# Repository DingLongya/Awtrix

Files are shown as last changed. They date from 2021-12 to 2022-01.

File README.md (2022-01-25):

# Awtrix

- 官网 https://awtrixdocs.blueforcer.de/
- 参考 UP 三三三三三文啊 视频：https://www.bilibili.com/video/BV1764y1f7pc
- 教程 https://bbs.iobroker.cn/t/topic/3888

## 成品展示

B 站演示地址：  https://b23.tv/A57vieg

这是还没有加外壳，3D打印外壳很贵很贵，想自己用木板做

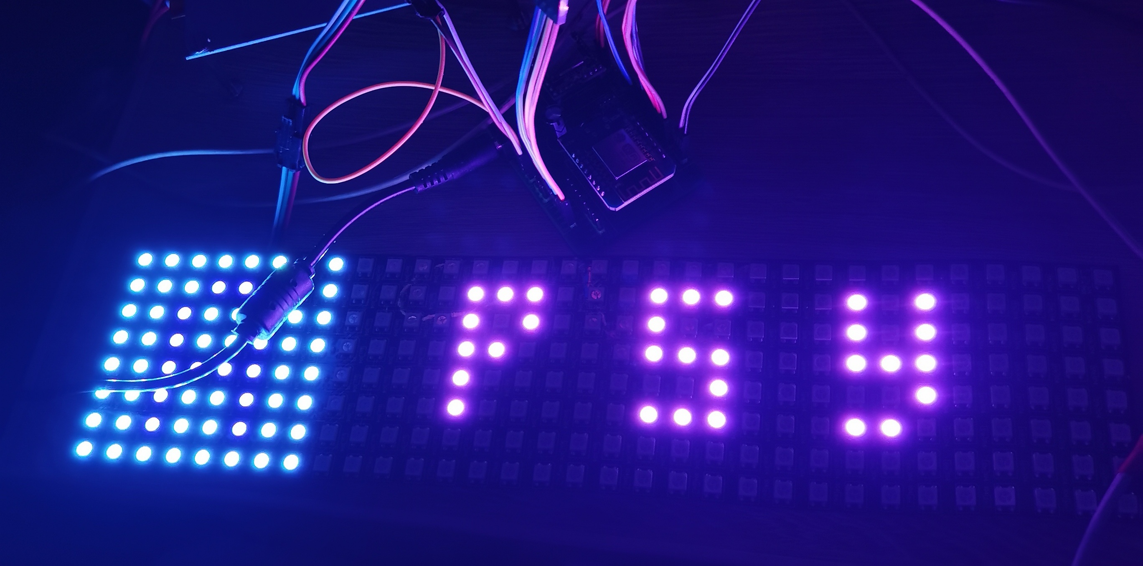
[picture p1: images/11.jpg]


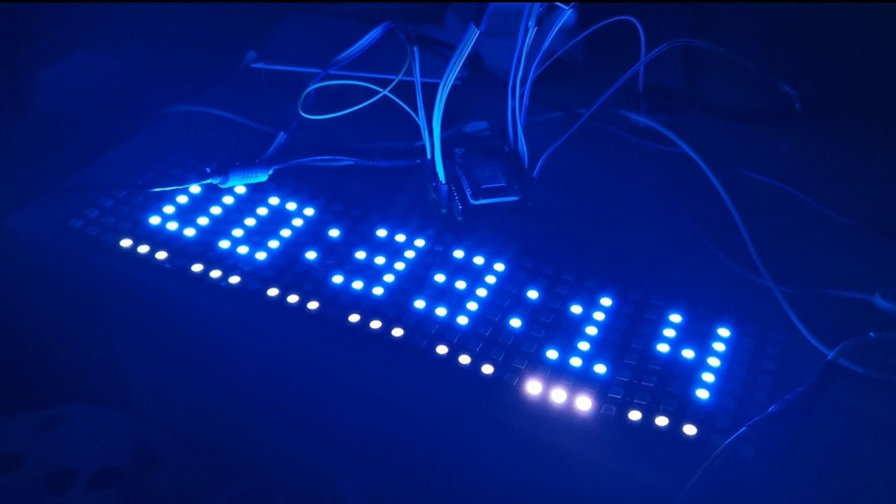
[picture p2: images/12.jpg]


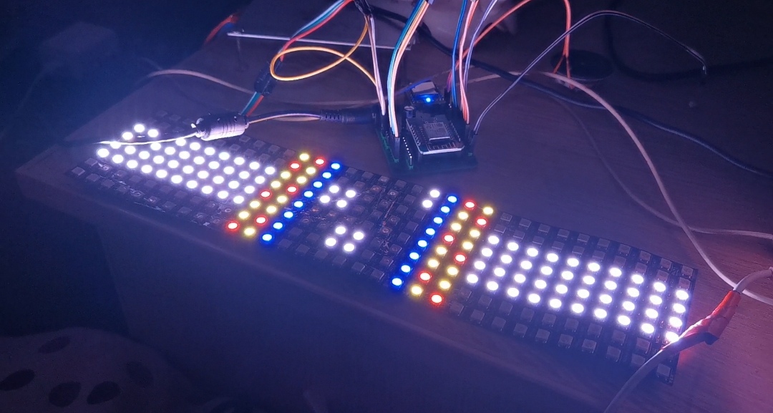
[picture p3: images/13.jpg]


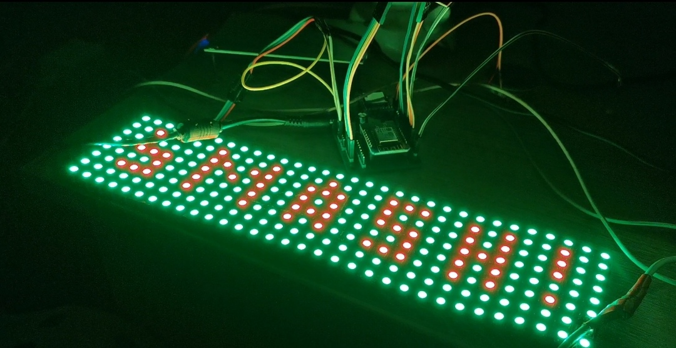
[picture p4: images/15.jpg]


外壳纯手工制作，买的胡桃木的木板

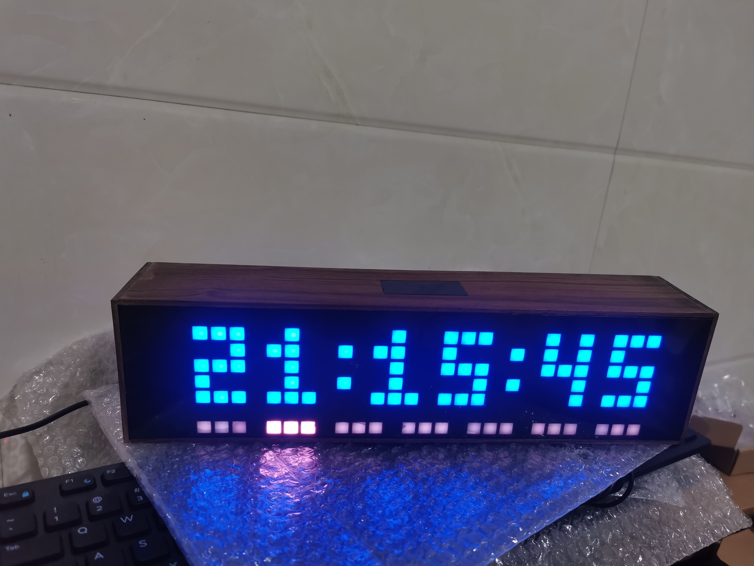
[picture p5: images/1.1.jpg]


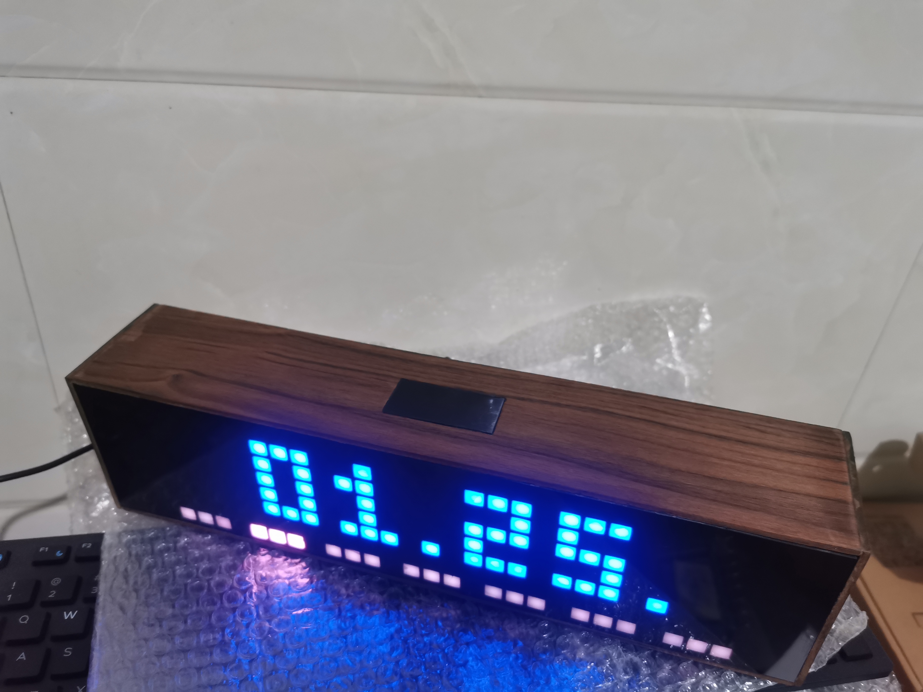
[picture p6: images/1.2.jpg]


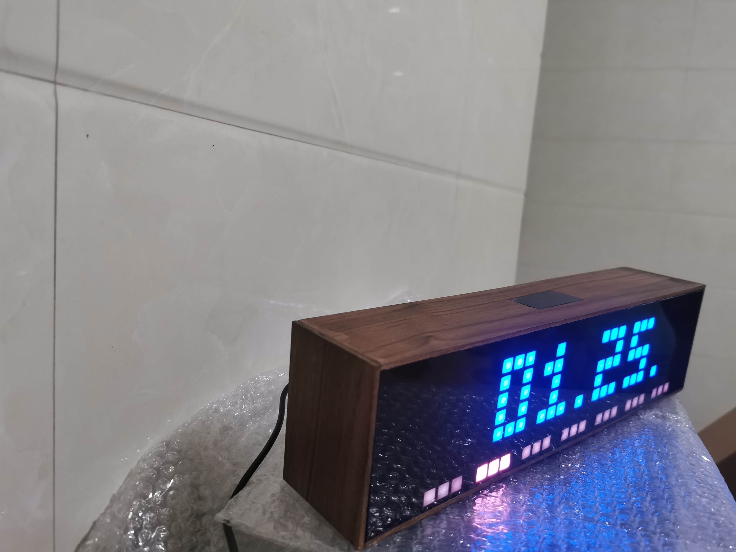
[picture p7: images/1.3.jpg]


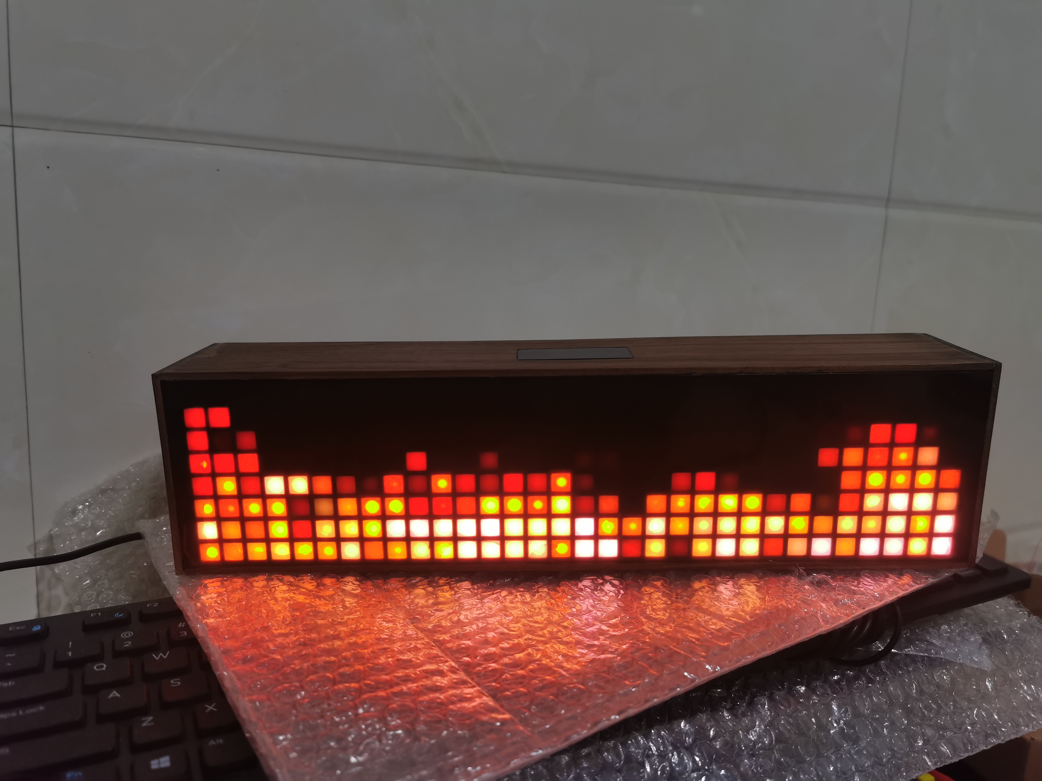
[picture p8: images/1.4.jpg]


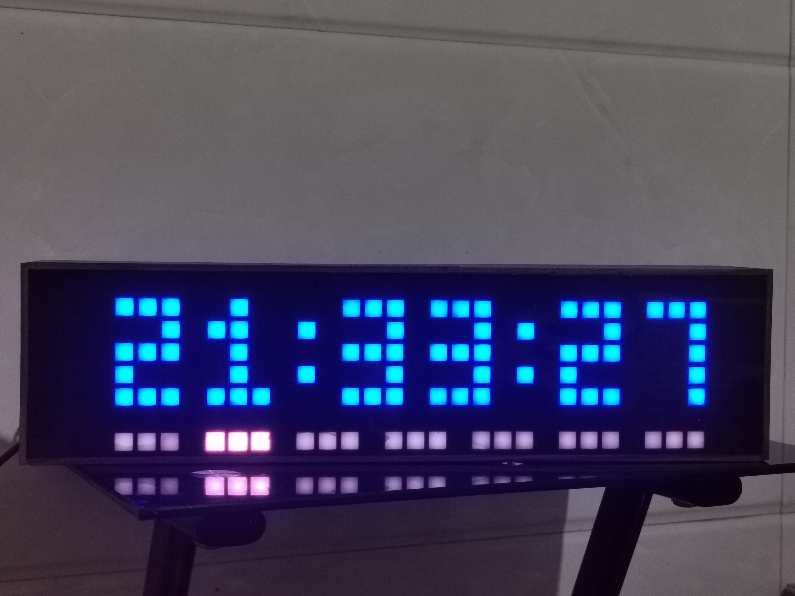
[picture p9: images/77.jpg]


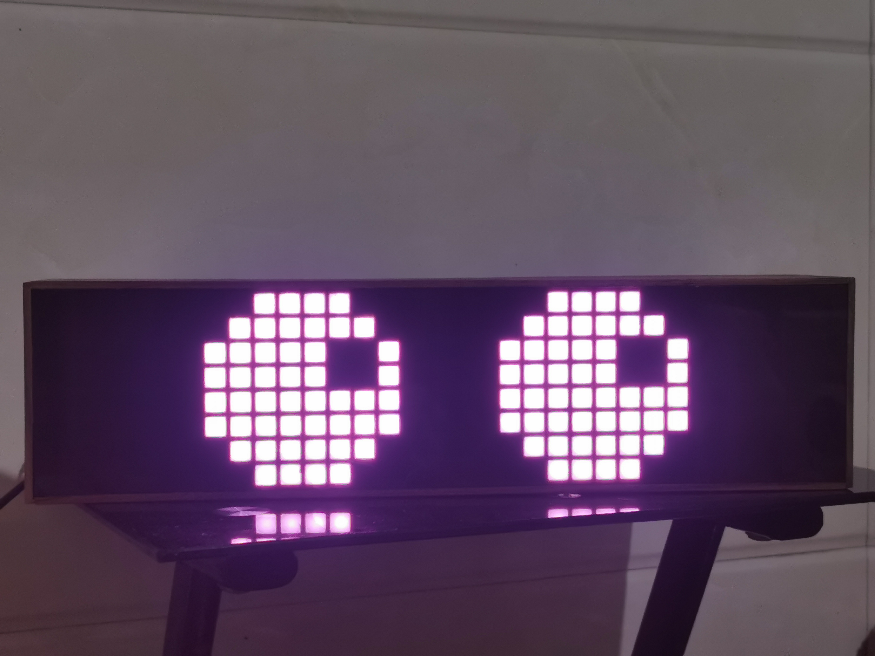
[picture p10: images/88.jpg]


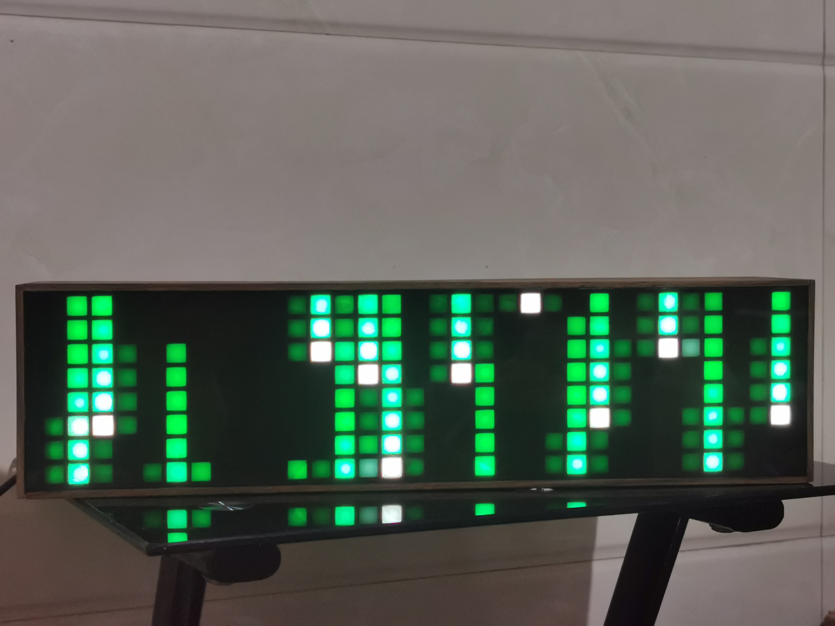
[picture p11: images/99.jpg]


## PCB

板子的 Gerber 文件在文件夹中：

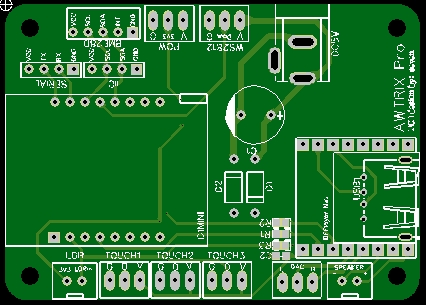
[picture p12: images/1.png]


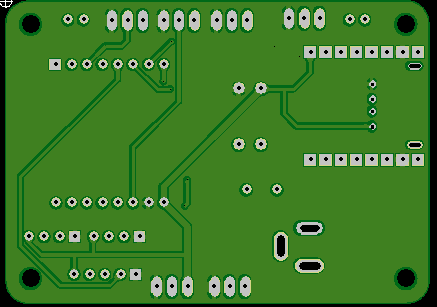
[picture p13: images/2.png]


## 元件

可以参考下面：

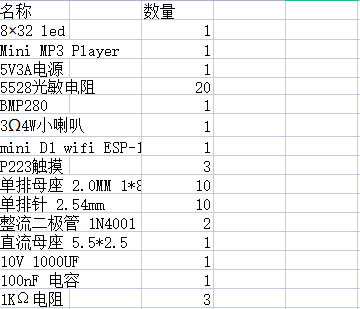
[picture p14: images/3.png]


## 焊接

焊接清单：

4个 1*8P 单母座（2.54） 注意是2.54的，不是2.0的

1个 10V/1000UF 8*12电解 1个

3个  1千欧的电阻

1个 100nF的电容

2个 1N4001（直插） 二极管

若干 单排针



## 按键

左按键

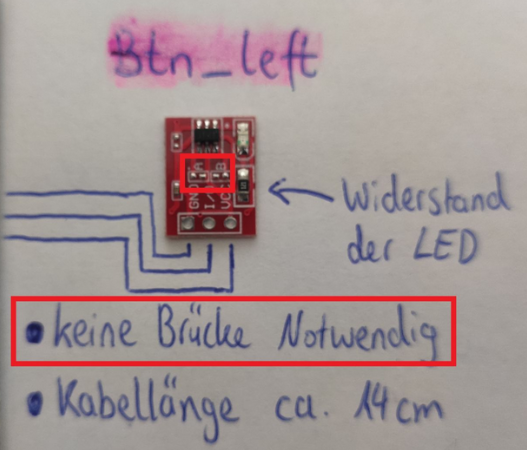
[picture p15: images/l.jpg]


中间按键

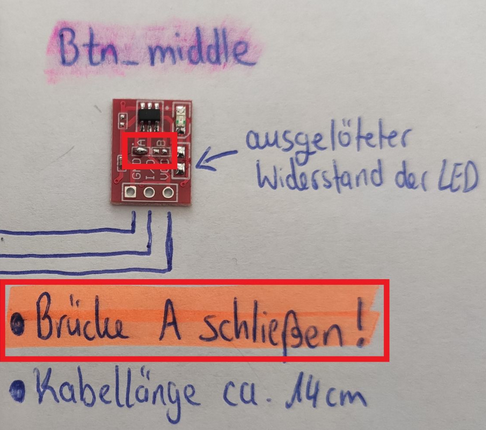
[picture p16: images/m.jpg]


右按键

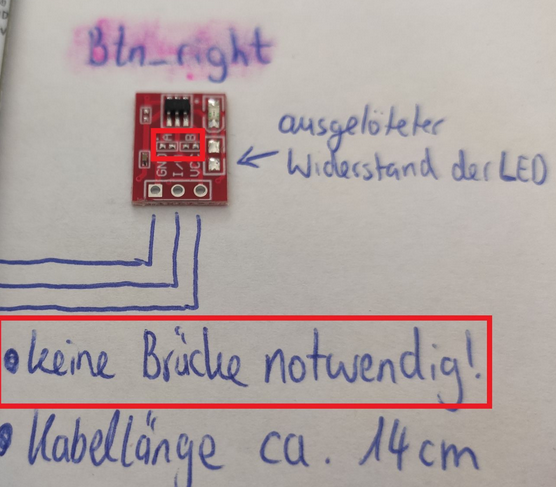
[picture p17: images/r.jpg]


## 组装

1个 Mini MP3 Player模块

1个 BMP280 模块

1个 5528光敏电阻

3个 P223触摸模块

1个 3瓦4欧喇叭

1个 WS2812

若干 杜邦线

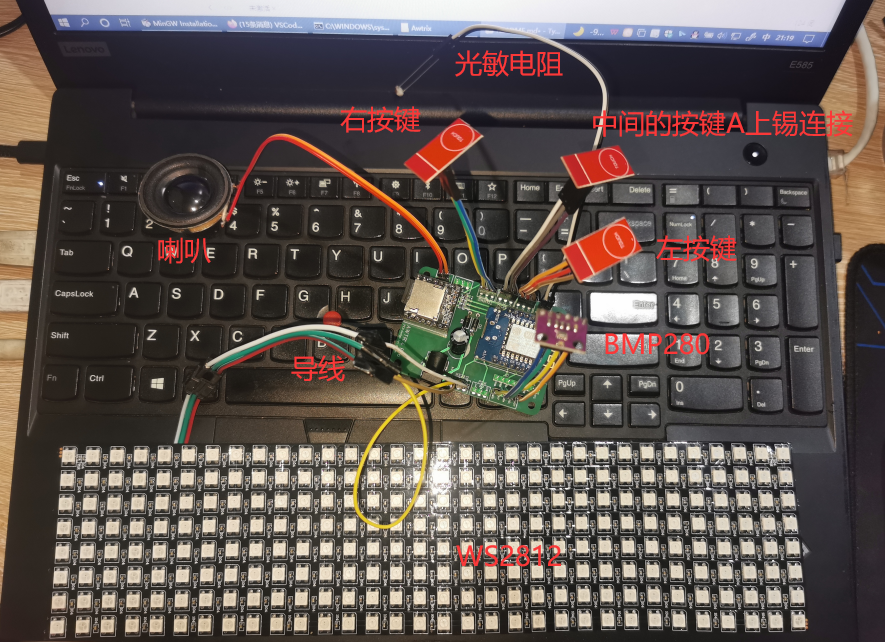
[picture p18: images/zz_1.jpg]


## 声音

格式化 TF 卡，将 MP3 文件放在 TF 卡下

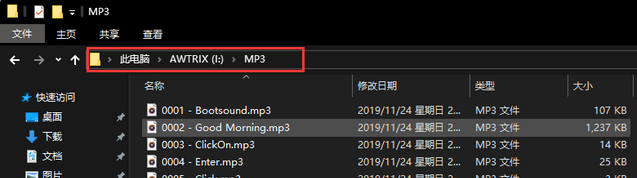
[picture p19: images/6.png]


## 烧录

	**1.** 启动 **ESP8266Flasher.exe** ，在“Config”选项卡中打开固件（点击齿轮选择固件） 

	**2.** 如果未自动检测到，请返回“操作”选项卡并设置正确的 Com-Port。 

	**3.** 单击“Flash”并等待该过程完成且左下角出现绿色复选标记。 

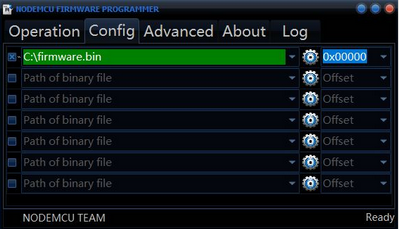
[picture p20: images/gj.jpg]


## 无线

首先给awtrix通电，没有连接到wifi的情况下会进入热点模式，使用手机或电脑搜索wifi，找到AWTRIX Controller这个ssid并加入，密码为awtrixxx

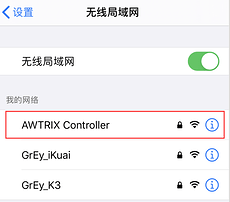
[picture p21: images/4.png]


此时应该会弹出一个web页面， 要是没有弹出，请使用浏览器打开地址172.217.28.1，并选择Configure Controller

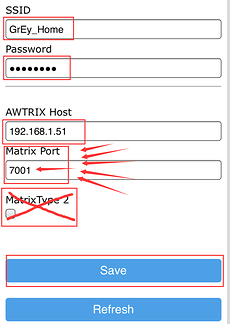
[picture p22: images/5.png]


切记不要勾选MatrixType 2，Matrix Port是连接服务器的端口号，默认是7001，不是7000，7000端口是web的端口，依次输入无线网名称，无线网密码，服务器的地址，然后点击Save，此时awtrix的设置都已经完成

## 服务器

安装JAVA环境后在 CMD 中运行如下命令（先`cd`到指定到 awtrix.jar 所在的文件夹下），执行`Host`文件夹的文件，开启服务器

`java -jar awtrix.jar`

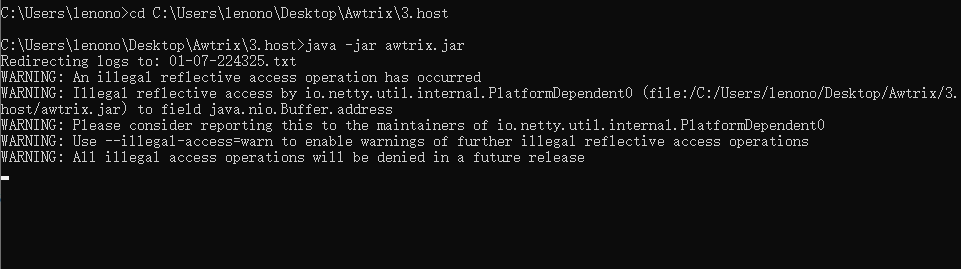
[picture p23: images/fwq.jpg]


`http:// [HOST-IP]:7000/` ： HOST-IP 主机本地连接的 IP，IP获取 CMD 输入 ipconfig

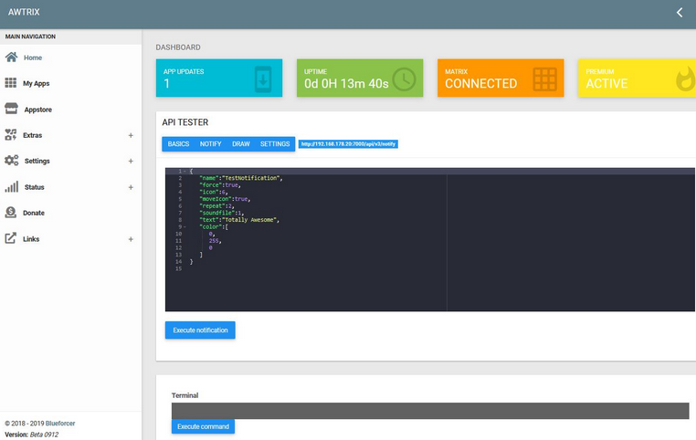
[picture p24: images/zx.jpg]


## 外壳

3D打印外壳太贵了，所以自己买木板做一个外壳，格栅和亚力克板是买的现成的，相关木板尺寸在文件夹 5.3D 中。

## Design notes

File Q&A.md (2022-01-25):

1. 装配好以后灯不亮

解决方法：看了电路图以后，发现 D1 mini 装反了，正确的是 d2 对应 WS2812 的 DIN；

2. 显示温度，湿度，压强 不准确

解决方法：发现原版使用的是 BME280 模块，而我买的是 BMP280，可能精度上有问题；

3. 要是使用服务器版本，那必须始终打开服务器，否则一直卡在 Host 页面上，离线版本得自己研究；

4. 外壳：因为3D打印太贵，所以自己买的模板制作，虽然钱少了，但是花费的时间多，不过，做出来的效果更好，大气；

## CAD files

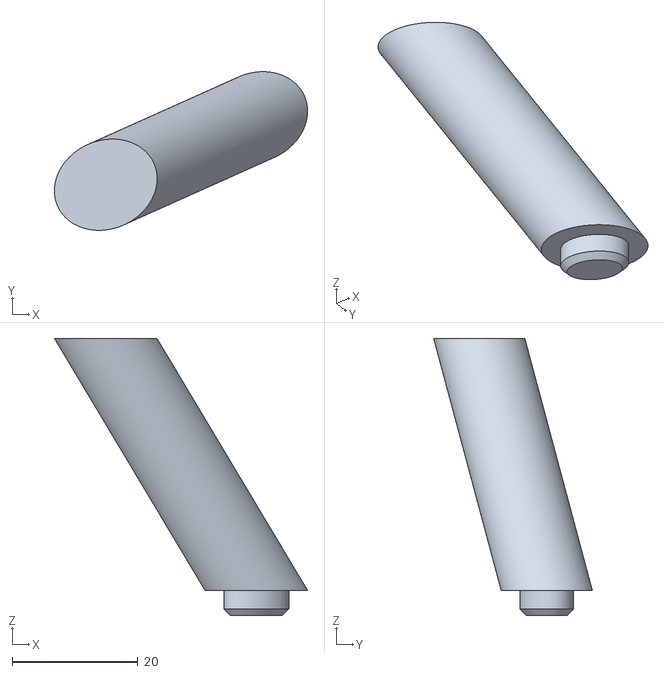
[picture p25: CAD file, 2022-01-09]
5.3D/原版3D外壳/腿1.stl
40.2 x 25.2 x 44.0

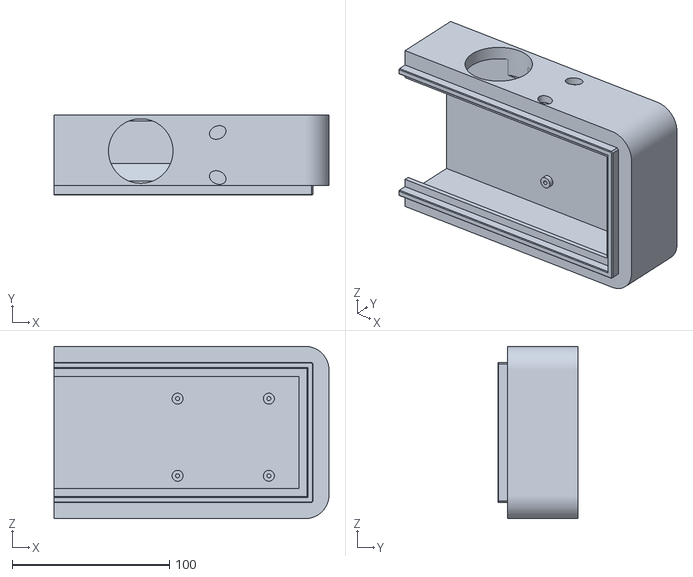
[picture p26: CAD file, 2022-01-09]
5.3D/原版3D外壳/底壳1.stl
174.7 x 51.0 x 109.4

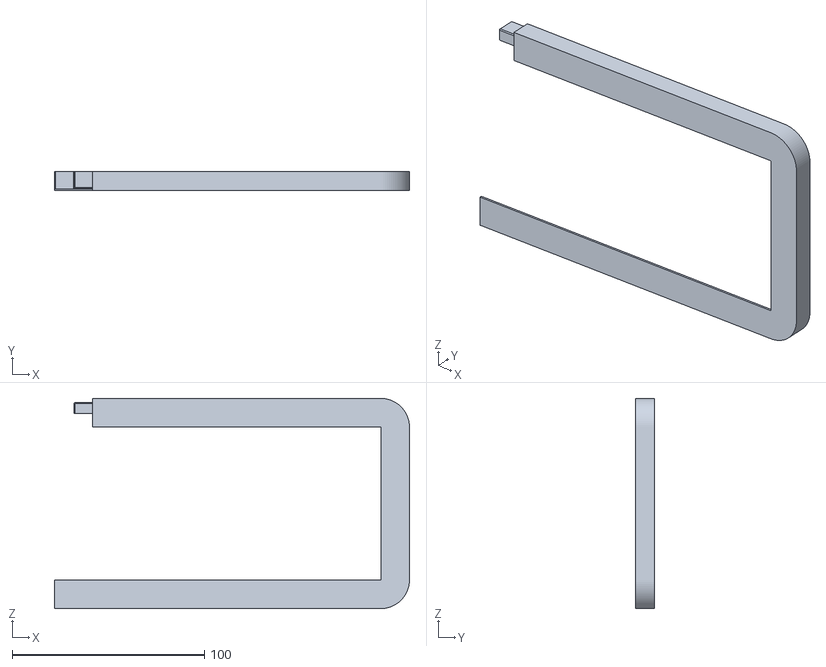
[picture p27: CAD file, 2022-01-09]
5.3D/原版3D外壳/顶盖 2-1.stl
184.7 x 10.1 x 109.4

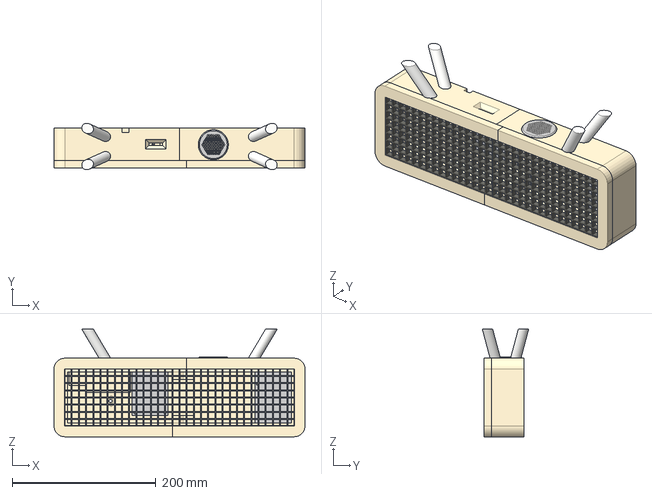
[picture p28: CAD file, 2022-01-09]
5.3D/原版3D外壳/AWTRIX PRO 拆分 v10.step
349.4 x 64.6 x 149.7 mm

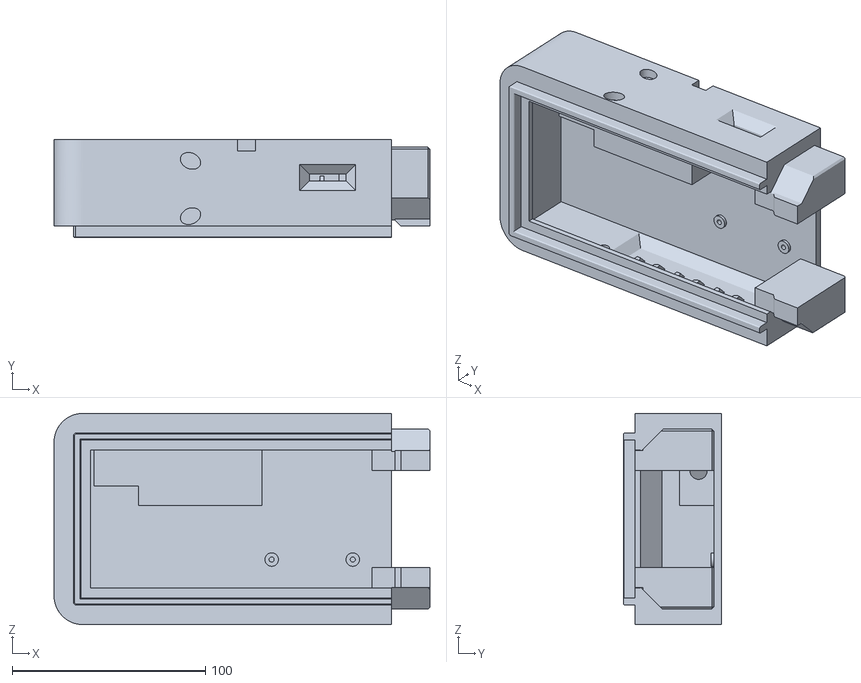
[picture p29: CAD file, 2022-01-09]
5.3D/原版3D外壳/底壳 2.stl
194.7 x 51.0 x 109.4

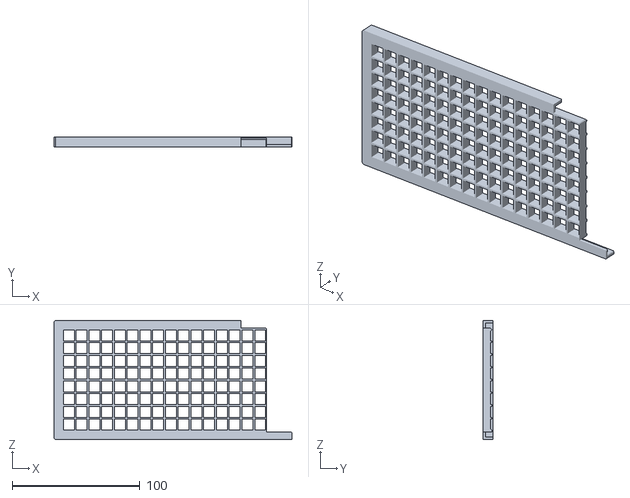
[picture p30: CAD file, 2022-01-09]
5.3D/原版3D外壳/格栅1.stl
186.6 x 8.00 x 93.4

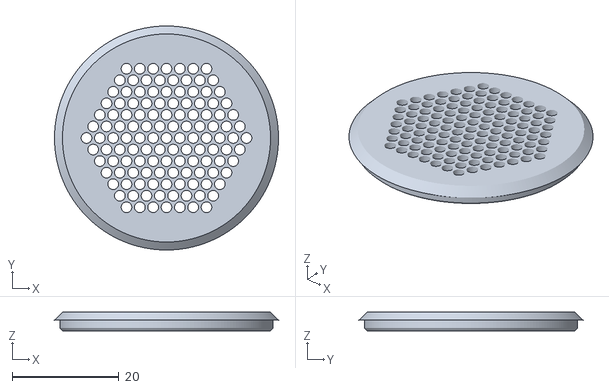
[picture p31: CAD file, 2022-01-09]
5.3D/原版3D外壳/扬声器罩.stl
42.0 x 42.0 x 3.50

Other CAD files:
5.3D/原版3D外壳/腿4.stl
5.3D/原版3D外壳/腿3.stl
5.3D/原版3D外壳/顶盖1-1.stl
5.3D/原版3D外壳/格栅2.stl
5.3D/原版3D外壳/腿2.stl
5.3D/木板制作/awtrix_草图.f3d

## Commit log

2022-01-06 add tips
    [Awtrix元件.xls]
2022-01-09 add 3D
    [AWTRIX PRO 拆分 v10.step, awtrix_草图.f3d, 底壳 2.stl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]
